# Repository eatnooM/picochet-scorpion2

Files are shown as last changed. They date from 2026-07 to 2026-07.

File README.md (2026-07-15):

# Picochet-Scorpion2

A dedicated microcontroller board for use with the OpenFIRE firmware, made to fit in the wonderfully comfortable Blaze Scorpion 2 shell

Picking up where the Picochet-TC1 left off, this board removes the solenoid feedback circuit and adds support for a few extra goodies that might make sense to add in a Scorpion 2, such as Neopixel LED (I have a 3D printable light pipe that takes the place of one of the wheels to adjust the laser in the stock Scorpion 2) and an analog stick (no plans to physically accommodate this in the shell but if you reckon you can make one fit, go nuts)

##  BOM

I'll copy the BOM into a nice table once it's settled.

## Thanks

OpenFIRE project - https://openfirelightgun.org/

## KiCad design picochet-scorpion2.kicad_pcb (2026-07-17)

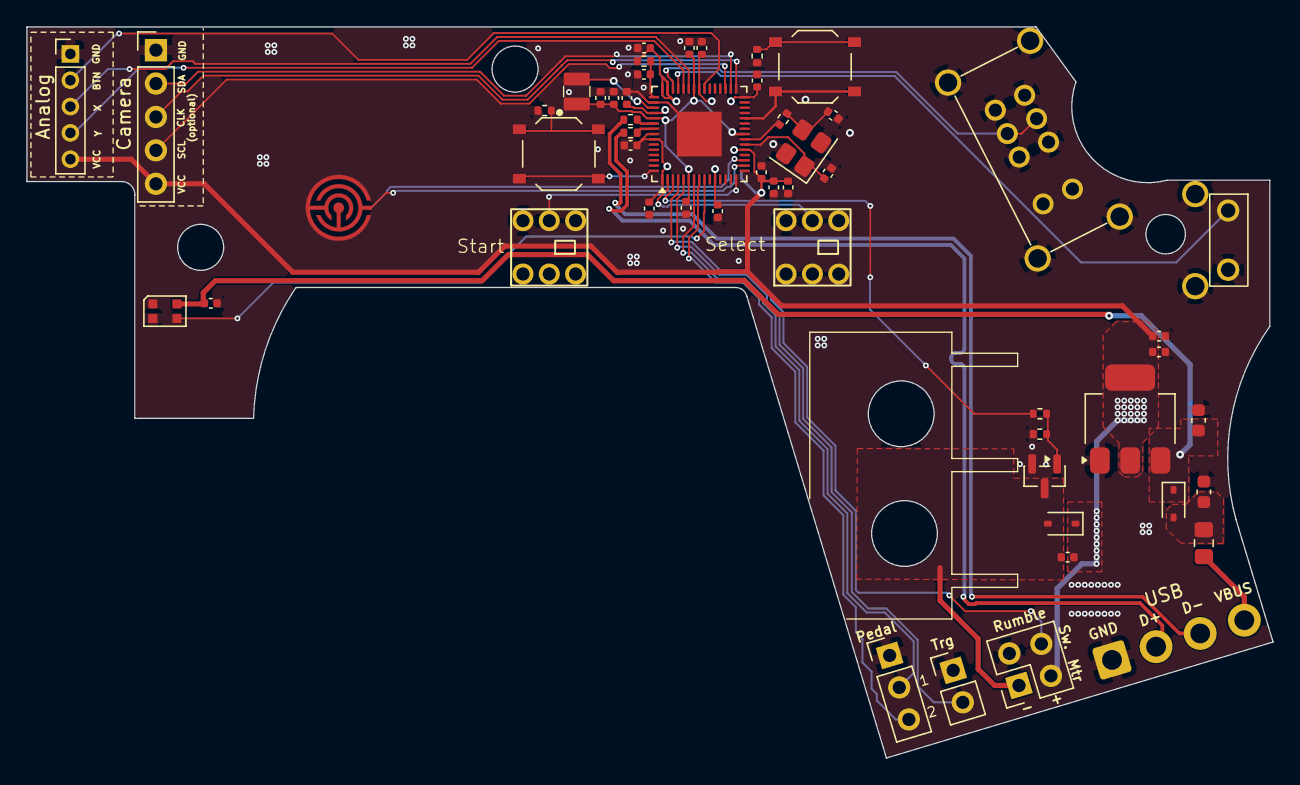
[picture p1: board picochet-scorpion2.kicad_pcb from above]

Board: 2 copper layers, 94.7 x 55.6 mm, 54 parts (1 on the bottom side), 39 nets.

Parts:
C1, C21: 10uF; C_0603_1608Metric
C3, C4: 30pF; C_0402_1005Metric
C5, C19: 10uF; C_0402_1005Metric
C6, C7, C9, C10: 4.7uF; C_0402_1005Metric
C8, C11, C12, C13, C14, C15, C16, C17, C18, C20, C23, C24, C25: 100nF; C_0402_1005Metric
D1: 1N5819WS; D_SOD-323
D2: BAT43WS; D_SOD-323
D3: WS2812B-2020; LED_WS2812B-2020_PLCC4_2.0x2.0mm
F1: PPTC-6V 500mA; Fuse_0805_2012Metric_Pad1.15x1.40mm_HandSolder
J1: Conn_02x02; PinHeader_2x02_P2.54mm_Vertical
J2: Conn_01x02; PinHeader_1x02_P2.54mm_Vertical
J3: Conn_01x04; USB-PTH-2.5MMOD-3.5mmSpacing
J4: Conn_01x03; PinHeader_1x03_P2.54mm_Vertical
J6: Conn_01x05; PinHeader_1x05_P2.54mm_Vertical
J8: Conn_01x05; PinHeader_1x05_P2.00mm_Vertical
L1: AOTA-B201610S3R3; L_0806_PolarityMark
Q1: AO3400A; SOT-23
R2, R4, R6: 1k; R_0402_1005Metric
R5, R7, R8: 33; R_0402_1005Metric
R14: 100; R_0402_1005Metric
R15: 10k; R_0402_1005Metric
SW1, SW2: SW_Push; SW_Push_1P1T_XKB_TS-1187A
SW3: SW_SP3T_Shielded; ModeSwitch-DP3T-MountingPoints
SW4, SW5: SW_Push; RubberDomeContacts-D5mm
SW6: SW_Push; ModeSwitch-Momentary
SW7, SW8: SW_DPDT; Switch-DPDT-5.8x5.8mm
U1: RP2354A; QFN-60-1EP_7x7mm_P0.4mm_EP3.4x3.4mm
U2: AMS1117-3.3; SOT-223-3_TabPin2
Y1: X322512MSB4SI; Crystal_SMD_3225-4Pin_3.2x2.5mm

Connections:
+1V1: C7.1, C8.2, C10.1, C11.2, L1.1, U1.6 (DVDD), U1.23 (DVDD), U1.39 (DVDD), U1.50 (VREG_FB)
+3V3: C5.1, C6.1, C12.1, C13.1, C14.1, C15.1, C16.1, C17.1, C18.1, C19.1, C20.1, C24.1, C25.2, D2.1 (K), J1.3, J6.5, J8.5, R5.1, U1.1 (IOVDD), U1.11 (IOVDD), U1.20 (IOVDD), U1.30 (IOVDD), U1.38 (IOVDD), U1.44 (ADC_AVDD), U1.45 (IOVDD), U1.49 (VREG_VIN), U1.53 (USB_OTP_VDD), U1.54 (QSPI_IOVDD), U2.2 (VO)
+5V: C21.1, D1.2 (A), F1.2
/AXIS_X: J8.3, U1.40 (GPIO26/ADC0)
/AXIS_Y: J8.4, U1.41 (GPIO27/ADC1)
/CAM_CLK: J6.3, U1.31 (GPIO19)
/CAM_SCL: J6.4, U1.33 (GPIO21)
/CAM_SDA: J6.2, U1.32 (GPIO20)
/LED_DI: D3.3 (DIN), U1.9 (GPIO6)
/RMB_GND: C24.2, D2.2 (A), J1.1, Q1.3 (D)
/RUMBLE: R14.1, U1.3 (GPIO1)
/USB_D+: J3.2, R7.1
/USB_D-: J3.3, R8.1
/VREG_LX: L1.2, U1.48 (VREG_LX)
/~AUTOFIRE: SW3.3, U1.43 (GPIO29/ADC3)
/~BTN_A: SW4.1, U1.17 (GPIO13)
/~BTN_B: SW5.1, U1.18 (GPIO14)
/~BTN_HOME: SW6.1, U1.42 (GPIO28/ADC2)
/~BTN_PEDAL_ALT: J4.3, U1.8 (GPIO5)
/~BTN_PEDAL: J4.2, U1.7 (GPIO4)
/~BTN_SELECT: SW8.5 (B), U1.2 (GPIO0)
/~BTN_START: SW7.5 (B), U1.15 (GPIO11)
/~BTN_STICK: J8.2, U1.37 (GPIO25)
/~BTN_TRIGGER: J2.2, U1.5 (GPIO3)
/~RESET: SW2.2, U1.26 (RUN)
/~RMB_ENABLE: J1.4, U1.4 (GPIO2)
GND: C1.2, C3.1, C4.1, C5.2, C6.2, C7.2, C8.1, C9.2, C10.2, C11.1, C12.2, C13.2, C14.2, C15.2, C16.2, C17.2, C18.2, C19.2, C20.2, C21.2, C23.2, C25.1, D3.2 (VSS), J1.2, J2.1, J3.1, J4.1, J6.1, J8.1, Q1.2 (S), R4.1, R6.1, R15.2, SW3.2, SW3.4, SW3.SH, SW4.2, SW5.2, SW6.2, SW6.SH (B), SW7.4 (A), SW8.4 (A), U1.47 (VREG_PGND), U1.61 (GND), U2.1 (GND), Y1.2 (G), Y1.4 (G)
unnamed: C4.2, R2.2, Y1.3
unnamed: Q1.1 (G), R14.2, R15.1
unnamed: R4.2, SW2.1
unnamed: R6.2, SW1.1
unnamed: R8.2, U1.51 (USB_DM)
unnamed: R7.2, U1.52 (USB_DP)
unnamed: C3.2, U1.21 (XIN), Y1.1
unnamed: R2.1, U1.22 (XOUT)
unnamed: SW1.2, U1.60 (~QSPI_SS)
VBUS: F1.1, J3.4
VREG_AVDD: C9.1, R5.2, U1.46 (VREG_AVDD)
VSYS: C1.1, C23.1, D1.1 (K), D3.4 (VDD), U2.3 (VI)

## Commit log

2026-05-23 Initial commit
    <_<
    [picochet-scorpion2.kicad_pcb, picochet-scorpion2.kicad_sch, rp2040_openfire_scorpion2.kicad_pcb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]
2026-05-24 v0.1 prototype
    [picochet-scorpion2.kicad_pcb, picochet-scorpion2.kicad_sch]
2026-07-15 v0.3 WIP
    [picochet-scorpion2.kicad_pcb, picochet-scorpion2.kicad_sch]
2026-07-17 Cost optomise for pcba (#1)
    * Cost optomise BOM and PCB layout for PCBA
    * Cost optomise
    * Change R7 & R8 to 33Ohm 0402 parts (correct issue of 27K)
    [picochet-scorpion2.kicad_pcb, picochet-scorpion2.kicad_sch]
